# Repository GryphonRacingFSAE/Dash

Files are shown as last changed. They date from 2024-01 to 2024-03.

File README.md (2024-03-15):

# Gryphon Racing Dash

## About

An electronic dash for Gryphon Racing Vechicles 22-Present

## Installing Dependencies

### Setup for Raspberry Pi

Install all missing packages
```bash
sudo apt-get install python cmake libgl-dev libx11-dev libx11-xcb-dev libxcb-util-dev m4 libffi-dev
```

Ensure that the can interface on the RPi is active
```bash
sudo ip link set can0 up type can bitrate 1000000 # 1 mbps speed
```

### Setup for Windows

- Install [Python](https://docs.python.org/3/using/windows.html#using-python-on-windows) & ensure it is installed to PATH.
- Install [CMake](https://cmake.org/download/) & ensure it is installed to PATH.
- Install [Visual Studio 2022](https://visualstudio.microsoft.com/) & ensure the Desktop Development C++ extension is installed.

### Setup for MacOS
- Ensure python3 version is up to date >3.7
- Install [CMake](https://cmake.org/download/) & ensure it is installed to PATH.

### Universal
- Install conan via pip
```bash
python -m pip install conan==1.60.0 # or python3 on MacOS
```

## Installing Build Dependencies

Run the conan install script (`-pr` is the profile being used, the options are found in [ConanProfiles](./ConanProfiles/))
```bash
# Windows VS2022
conan install . -if build -pr:h=ConanProfiles/VS2022-Debug.ini -pr:b=ConanProfiles/VS2022-Debug.ini --build=missing -o dev="front"

# MacOS clang 14
conan install . -if build -pr:h=ConanProfiles/MacOS-clang-Debug.ini -pr:b=ConanProfiles/MacOS-clang-Debug.ini --build=missing -o dev="front"

# RPi 4b (gcc 10.2)
conan install . -if build -pr:h=ConanProfiles/pi4b-Debug.ini -pr:b=ConanProfiles/pi4b-Debug.ini --build=missing -o dev="full"

# RPi 1.2 b+ (gcc 10.2)
conan install . -if build -pr:h ConanProfiles/pib+-Release.ini -pr:b ConanProfiles/pib+-Release.ini --build=missing

# Linux gcc 12
conan install . -if build -pr:h=ConanProfiles/Linux-gcc-12-Debug.ini -pr:b=ConanProfiles/Linux-gcc-12-Debug.ini --build=missing -o dev="full"
```

* If building with `dev="back"`, Qt is not a requirement

## Building
- Run the conan build script & executables will be found in the build/bin folder.

```bash
conan build -if build .
```

## Running

```bash
source build/activate_run.sh # RPi (maybe required on other linux distros)
./build/Debug/bin/GryphonDash #(This runs the executable on RPi)
./build/bin/GryphonDash.exe #(This is to run the executable on windows)
source build/deactivate_run.sh # RPi (maybe required on other linux distros)
```

## Branch rules

- Name your branch as follows: `firstname/branchtopic`, ex. `dallas/move-from-previous-repo`
- `main` is a protected branch, and thus needs a PR to approve merging with it.

## CAN reservations

| Item | Reserved CAN Addresses |
|-|-|
| Motor Controller | 0x0A0-0x0CF |
| VCU | 0x0D0-0x0DF |
| BMS | 0x0E0-0x0EF |

## Building For RPI1.2

```bash
docker build
docker run
docker cp # copy artifacts back to userspace
```

## Resources

* [<linux/can.h>](https://github.com/torvalds/linux/blob/master/include/uapi/linux/can.h)
* [SocketCAN Intro](https://copperhilltech.com/what-is-socketcan/)
* [PiCAN1](https://copperhilltech.com/pican-with-gps-gyro-accelerometer-can-bus-board-for-raspberry-pi/)/[PiCAN2](https://copperhilltech.com/pican-2-can-bus-interface-for-raspberry-pi/)
* [Raspberry Pi w/ CanBus](https://www.hackster.io/youness/how-to-connect-raspberry-pi-to-can-bus-b60235)
* Not used, but good cross reference for the SocketCAN intro: [socketcan-cpp](https://github.com/siposcsaba89/socketcan-cpp)

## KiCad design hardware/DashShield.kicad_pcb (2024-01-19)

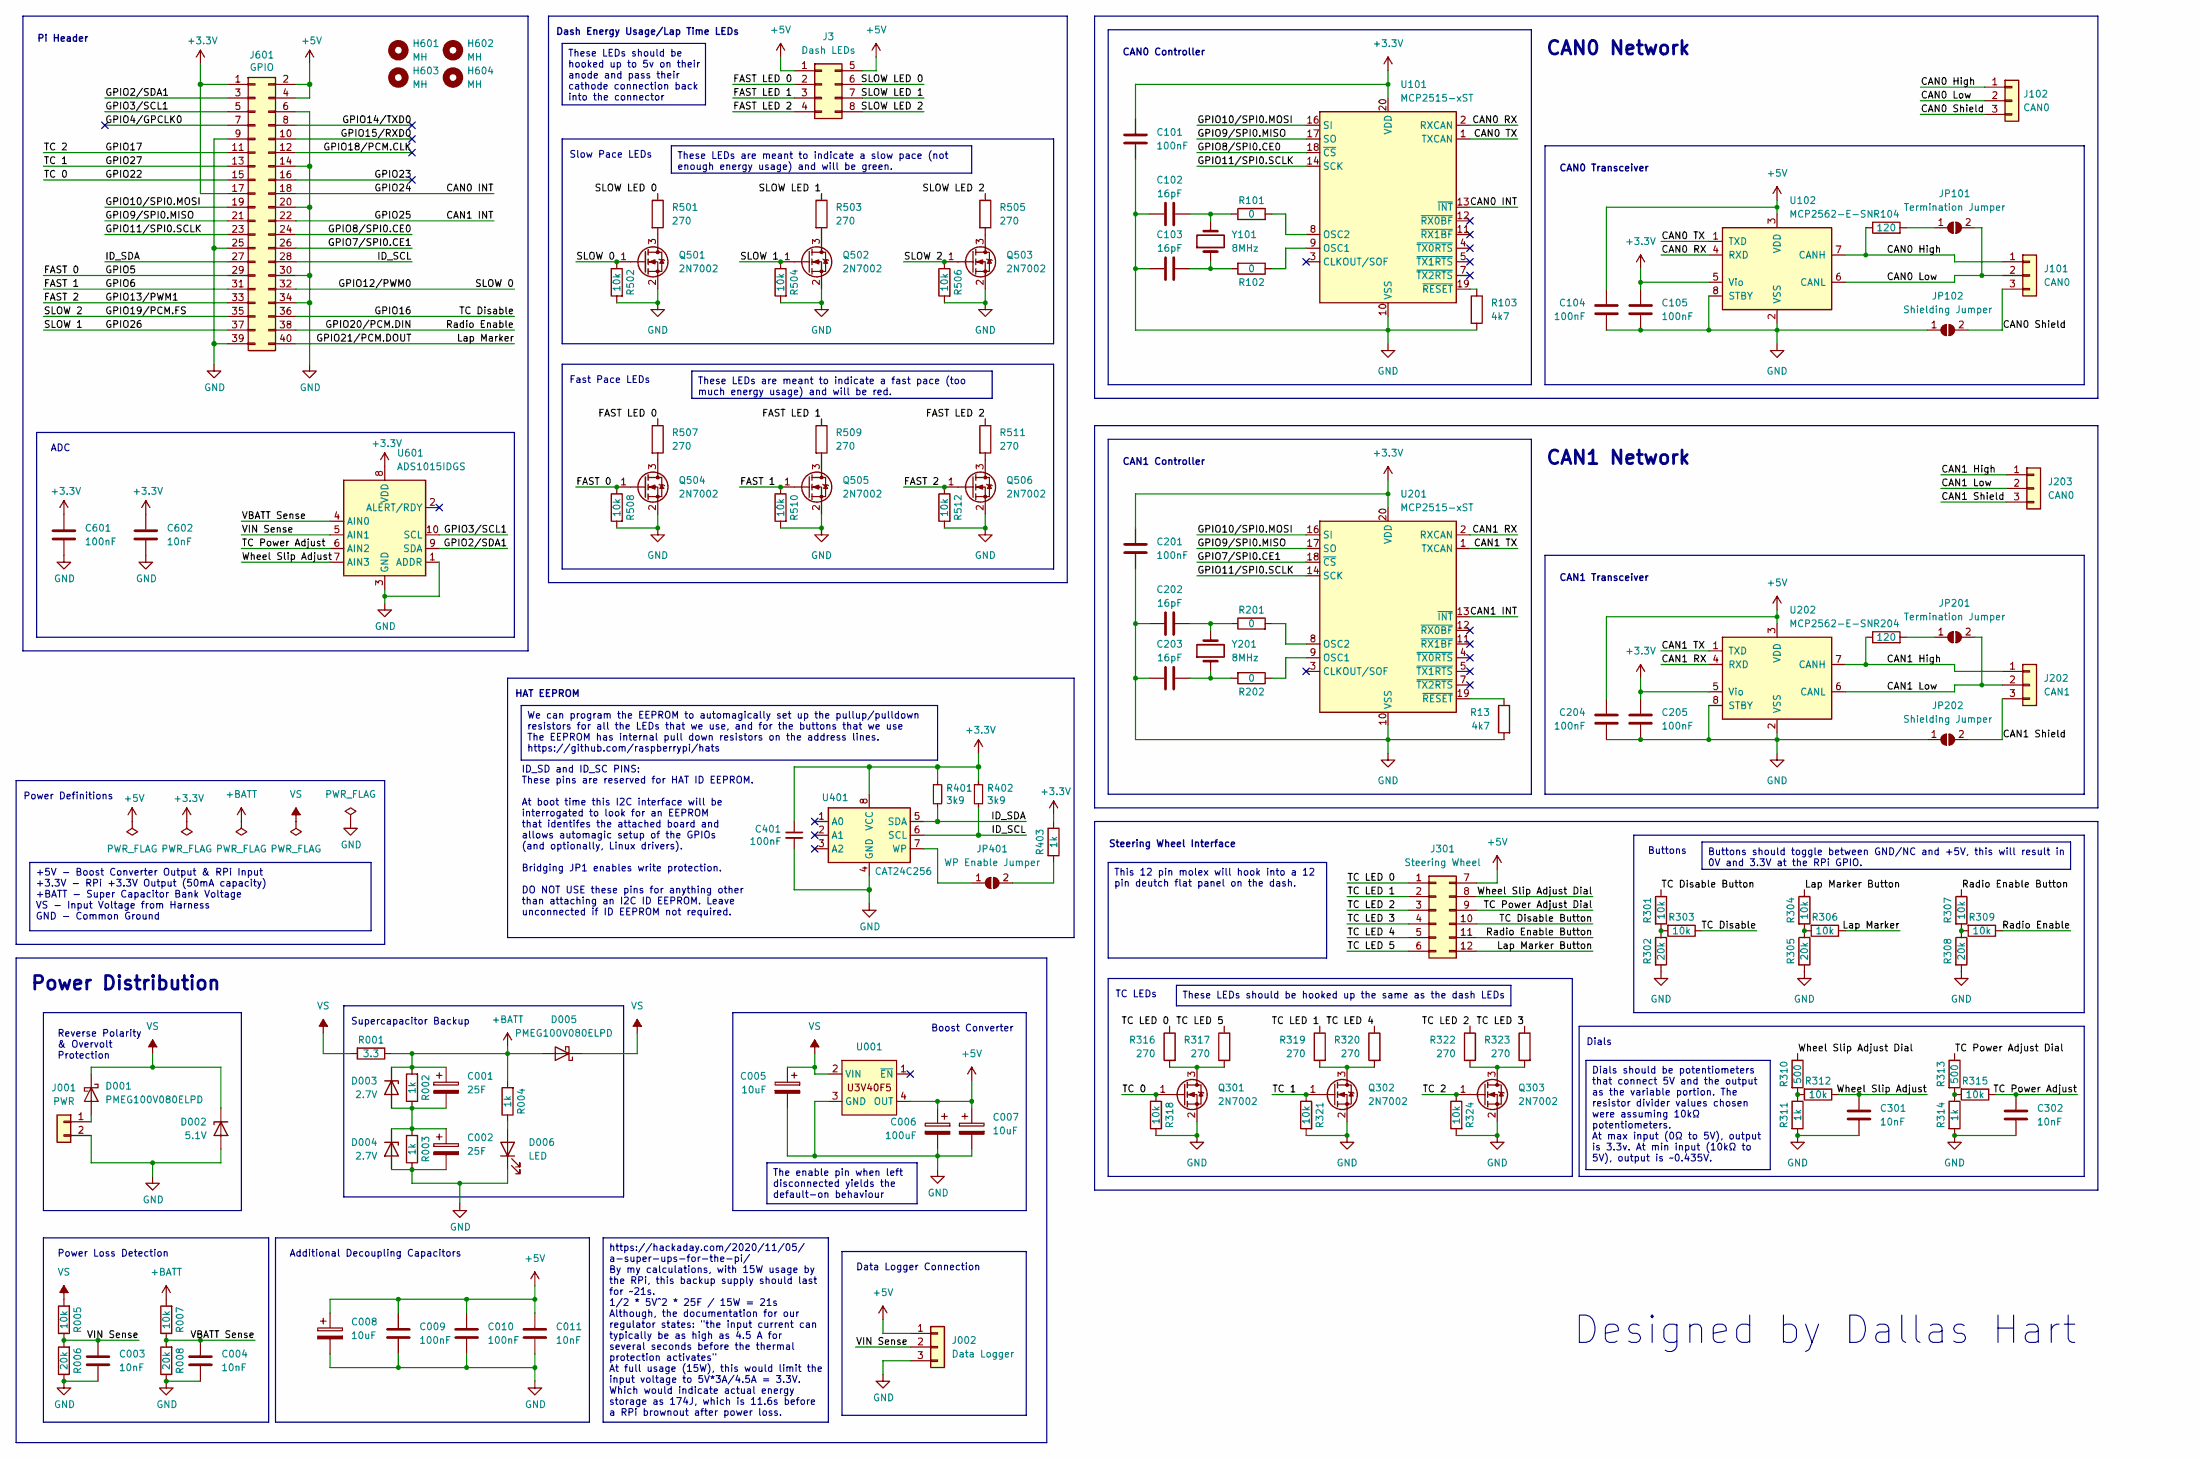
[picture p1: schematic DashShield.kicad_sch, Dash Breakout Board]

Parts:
C001, C002: 25F; CP_Radial_D16.0mm_P7.50mm
C003, C004, C011, C301, C302, C602: 10nF; C_0603_1608Metric
C005, C007, C008: 10uF; CP_Radial_D5.0mm_P2.50mm
C006: 100uF; CP_Radial_D5.0mm_P2.50mm
C009, C010, C101, C104, C105, C201, C204, C205, C401, C601: 100nF; C_0603_1608Metric
C102, C103, C202, C203: 16pF; C_0603_1608Metric
D001, D005: PMEG100V080ELPD; Nexperia_CFP15_SOT-1289
D002: 5.1V; D_SMA
D003, D004: 2.7V; SOT-23
D006: LED; LED_0603_1608Metric
H601, H602, H603, H604: MH; MountingHole_2.7mm_M2.5_Pad
J001: PWR; Molex_Micro-Fit_3.0_43650-0215_1x02_P3.00mm_Vertical
J002: Data Logger; Molex_Micro-Fit_3.0_43650-0315_1x03_P3.00mm_Vertical
J3: Dash LEDs; Molex_Micro-Fit_3.0_43045-0812_2x04_P3.00mm_Vertical
J101, J102, J203: CAN0; Molex_Micro-Fit_3.0_43650-0315_1x03_P3.00mm_Vertical
J202: CAN1; Molex_Micro-Fit_3.0_43650-0315_1x03_P3.00mm_Vertical
J301: Steering Wheel; Molex_Micro-Fit_3.0_43045-1212_2x06_P3.00mm_Vertical
J601: GPIO; PinSocket_2x20_P2.54mm_Vertical
JP101, JP201: Termination Jumper; SolderJumper-2_P1.3mm_Open_RoundedPad1.0x1.5mm
JP102, JP202: Shielding Jumper; SolderJumper-2_P1.3mm_Open_RoundedPad1.0x1.5mm
JP401: WP Enable Jumper; SolderJumper-2_P1.3mm_Open_RoundedPad1.0x1.5mm
Q301, Q302, Q303, Q501, Q502, Q503, Q504, Q505, Q506: 2N7002; SOT-23
R001: 3.3; R_0603_1608Metric
R002, R003, R004, R311, R314, R403: 1k; R_0603_1608Metric
R005, R007, R301, R303, R304, R306, R307, R309, R312, R315, R318, R321, R324, R502, R504, R506, R508, R510, R512: 10k; R_0603_1608Metric
R006, R008, R302, R305, R308: 20k; R_0603_1608Metric
R13, R103: 4k7; R_0603_1608Metric
R101, R102, R201, R202: 0; R_0603_1608Metric
R104, R204: 120; R_0603_1608Metric
R310, R313: 500; R_0603_1608Metric
R316, R317, R319, R320, R322, R323, R501, R503, R505, R507, R509, R511: 270; R_0603_1608Metric
R401, R402: 3k9; R_0603_1608Metric
U001: U3V40x
U101, U201: MCP2515-xST; TSSOP-20_4.4x6.5mm_P0.65mm
U102, U202: MCP2562-E-SN; SOIC-8_3.9x4.9mm_P1.27mm
U401: CAT24C256; SOIC-8_3.9x4.9mm_P1.27mm
U601: ADS1015IDGS; TSSOP-10_3x3mm_P0.5mm
Y101, Y201: 8MHz; Crystal_C38-LF_D3.0mm_L8.0mm_Vertical

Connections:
+3.3V: C101.1, C105.1, C201.1, C205.1, C401.1, C601.1, C602.1, J601.1, J601.17, R401.1, R402.1, R403.1, U101.20 (VDD), U102.5 (Vio), U201.20 (VDD), U202.5 (Vio), U401.8 (VCC), U601.8 (VDD)
+5V: C006.1, C007.1, C008.1, C009.1, C010.1, C011.1, C104.1, C204.1, J002.1, J3.1, J3.5, J301.7, J601.2, J601.4, U001.4 (OUT), U102.3 (VDD), U202.3 (VDD)
+BATT: C001.1, D003.3 (K), D005.1 (A), D005.2 (A), R001.1, R002.2, R004.2, R007.2
/CAN0 High: J101.1, J102.1, R104.1, U102.7 (CANH)
/CAN0 INT: J601.18, U101.13 (~INT)
/CAN0 Low: J101.2, J102.2, JP101.2 (B), U102.6 (CANL)
/CAN0 RX: U101.2 (RXCAN), U102.4 (RXD)
/CAN0 Shield: J101.3, J102.3, JP102.2 (B)
/CAN0 TX: U101.1 (TXCAN), U102.1 (TXD)
/CAN1 High: J202.1, J203.1, R204.1, U202.7 (CANH)
/CAN1 INT: J601.22, U201.13 (~INT)
/CAN1 Low: J202.2, J203.2, JP201.2 (B), U202.6 (CANL)
/CAN1 RX: U201.2 (RXCAN), U202.4 (RXD)
/CAN1 Shield: J202.3, J203.3, JP202.2 (B)
/CAN1 TX: U201.1 (TXCAN), U202.1 (TXD)
/FAST 0: J601.29, Q504.1 (G), R508.1
/FAST 1: J601.31, Q505.1 (G), R510.1
/FAST 2: J601.33, Q506.1 (G), R512.1
/FAST LED 0: J3.2, R507.1
/FAST LED 1: J3.3, R509.1
/FAST LED 2: J3.4, R511.1
/GPIO2/SDA1: J601.3, U601.9 (SDA)
/GPIO3/SCL1: J601.5, U601.10 (SCL)
/GPIO4/GPCLK0: J601.7
/GPIO7/SPI0.CE1: J601.26, U201.18 (~CS)
/GPIO8/SPI0.CE0: J601.24, U101.18 (~CS)
/GPIO9/SPI0.MISO: J601.21, U101.17 (SO), U201.17 (SO)
/GPIO10/SPI0.MOSI: J601.19, U101.16 (SI), U201.16 (SI)
/GPIO11/SPI0.SCLK: J601.23, U101.14 (SCK), U201.14 (SCK)
/GPIO12/PWM0: J601.32, Q501.1 (G), R502.1
/GPIO14/TXD0: J601.8
/GPIO15/RXD0: J601.10
/GPIO16: J601.36, R303.1
/GPIO17: J601.11, Q303.1 (G), R324.1
/GPIO18/PCM.CLK: J601.12
/GPIO19/PCM.FS: J601.35, Q503.1 (G), R506.1
/GPIO20/PCM.DIN: J601.38, R309.1
/GPIO21/PCM.DOUT: J601.40, R306.1
/GPIO22: J601.15, Q301.1 (G), R318.1
/GPIO23: J601.16
/GPIO26: J601.37, Q502.1 (G), R504.1
/GPIO27: J601.13, Q302.1 (G), R321.1
/ID_SCL: J601.28, R402.2, U401.6 (SCL)
/ID_SDA: J601.27, R401.2, U401.5 (SDA)
/Lap Marker Button: J301.12, R304.1
/Radio Enable Button: J301.11, R307.1
/SLOW LED 0: J3.6, R501.1
/SLOW LED 1: J3.7, R503.1
/SLOW LED 2: J3.8, R505.1
/TC Disable Button: J301.10, R301.1
/TC LED 0: J301.1, R316.1
/TC LED 1: J301.2, R319.1
/TC LED 2: J301.3, R322.1
/TC LED 3: J301.4, R323.1
/TC LED 4: J301.5, R320.1
/TC LED 5: J301.6, R317.1
/TC Power Adjust: C302.1, R315.1, U601.6 (AIN2)
/TC Power Adjust Dial: J301.9, R313.1
/VBATT Sense: C004.1, R007.1, R008.2, U601.4 (AIN0)
/VIN Sense: C003.1, J002.2, R005.1, R006.2, U601.5 (AIN1)
/Wheel Slip Adjust: C301.1, R312.1, U601.7 (AIN3)
/Wheel Slip Adjust Dial: J301.8, R310.1
GND: C002.2, C003.2, C004.2, C005.2, C006.2, C007.2, C008.2, C009.2, C010.2, C011.2, C101.2, C102.2, C103.1, C104.2, C105.2, C201.2, C202.2, C203.1, C204.2, C205.2, C301.2, C302.2, C401.2, C601.2, C602.2, D002.2 (A), D004.1 (A), D006.1 (K), J001.2, J002.3, J601.6, J601.9, J601.14, J601.20, J601.25, J601.30, J601.34, J601.39, JP102.1 (A), JP202.1 (A), Q301.2 (S), Q302.2 (S), Q303.2 (S), Q501.2 (S), Q502.2 (S), Q503.2 (S), Q504.2 (S), Q505.2 (S), Q506.2 (S), R003.1, R006.1, R008.1, R13.2, R103.2, R302.2, R305.2, R308.2, R311.2, R314.2, R318.2, R321.2, R324.2, R502.2, R504.2, R506.2, R508.2, R510.2, R512.2, U001.3 (GND), U101.10 (VSS), U102.2 (VSS), U102.8 (STBY), U201.10 (VSS), U202.2 (VSS), U202.8 (STBY), U401.4 (GND), U601.1 (ADDR), U601.3 (GND)
unnamed: C102.1, R101.1, Y101.2
unnamed: C103.2, R102.2, Y101.1
unnamed: C202.1, R201.1, Y201.2
unnamed: C203.2, R202.2, Y201.1
unnamed: C001.2, C002.1, D003.1 (A), D004.3 (K), R002.1, R003.2
unnamed: D006.2 (A), R004.1
unnamed: D001.1 (A), D001.2 (A), J001.1
unnamed: JP101.1 (A), R104.2
unnamed: JP201.1 (A), R204.2
unnamed: JP401.1 (A), U401.7 (WP)
unnamed: JP401.2 (B), R403.2
unnamed: Q301.3 (D), R316.2, R317.2
unnamed: Q302.3 (D), R319.2, R320.2
unnamed: Q303.3 (D), R322.2, R323.2
unnamed: Q501.3 (D), R501.2
unnamed: Q502.3 (D), R503.2
unnamed: Q503.3 (D), R505.2
unnamed: Q504.3 (D), R507.2
unnamed: Q505.3 (D), R509.2
unnamed: Q506.3 (D), R511.2
unnamed: R301.2, R302.1, R303.2
unnamed: R304.2, R305.1, R306.2
unnamed: R307.2, R308.1, R309.2
unnamed: R310.2, R311.1, R312.2
unnamed: R313.2, R314.1, R315.2
unnamed: R102.1, U101.9 (OSC1)
unnamed: R101.2, U101.8 (OSC2)
unnamed: R103.1, U101.19 (~RESET)
unnamed: R202.1, U201.9 (OSC1)
unnamed: R201.2, U201.8 (OSC2)
unnamed: R13.1, U201.19 (~RESET)
VS: C005.1, D001.3 (K), D002.1 (K), D005.3 (K), R001.2, R005.2, U001.2 (VIN)

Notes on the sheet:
https://hackaday.com/2020/11/05/ a-super-ups-for-the-pi/ By my calculations, with 15W usage by the RPi, this backup supply should last for ~21s. 1/2 * 5V^2 * 25F / 15W = 21s Although, the documentation for our regulator states: "the input current can typically be as high as 4.5 A for several second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
These LEDs should be hooked up to 5v on their anode and pass their cathode connection back into the connector
Buttons should toggle between GND/NC and +5V, this will result in 0V and 3.3V at the RPi GPIO.
We can program the EEPROM to automagically set up the pullup/pulldown resistors for all the LEDs that we use, and for the buttons that we use The EEPROM has internal pull down resistors on the address lines. https://github.com/raspberrypi/hats
The enable pin when left disconnected yields the default-on behaviour
These LEDs are meant to indicate a slow pace (not enough energy usage) and will be green.
Dials should be potentiometers that connect 5V and the output as the variable portion. The resistor divider values chosen were assuming 10kΩ potentiometers. At max input (0Ω to 5V), output is 3.3v. At min input (10kΩ to 5V), output is ~0.435V.
This 12 pin molex will hook into a 12 pin deutch flat panel on the dash.
+5V - Boost Converter Output & RPi Input +3.3V - RPi +3.3V Output (50mA capacity) +BATT - Super Capacitor Bank Voltage VS - Input Voltage from Harness GND - Common Ground
These LEDs should be hooked up the same as the dash LEDs
These LEDs are meant to indicate a fast pace (too much energy usage) and will be red.
Power Loss Detection
Power Definitions
CAN1 Controller
Reverse Polarity & Overvolt Protection
Dials
Designed by Dallas Hart
ID_SD and ID_SC PINS: These pins are reserved for HAT ID EEPROM. At boot time this I2C interface will be interrogated to look for an EEPROM that identifes the attached board and allows automagic setup of the GPIOs (and optionally, Linux drivers). Bridging JP1 enables write protection. DO NOT USE th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
ADC
Data Logger Connection
Buttons
Power Distribution
Fast Pace LEDs
TC LEDs
CAN1 Transceiver
Supercapacitor Backup
Steering Wheel Interface
CAN1 Network
Dash Energy Usage/Lap Time LEDs
HAT EEPROM
Slow Pace LEDs
CAN0 Network
Pi Header
CAN0 Transceiver
CAN0 Controller
Additional Decoupling Capacitors
Boost Converter

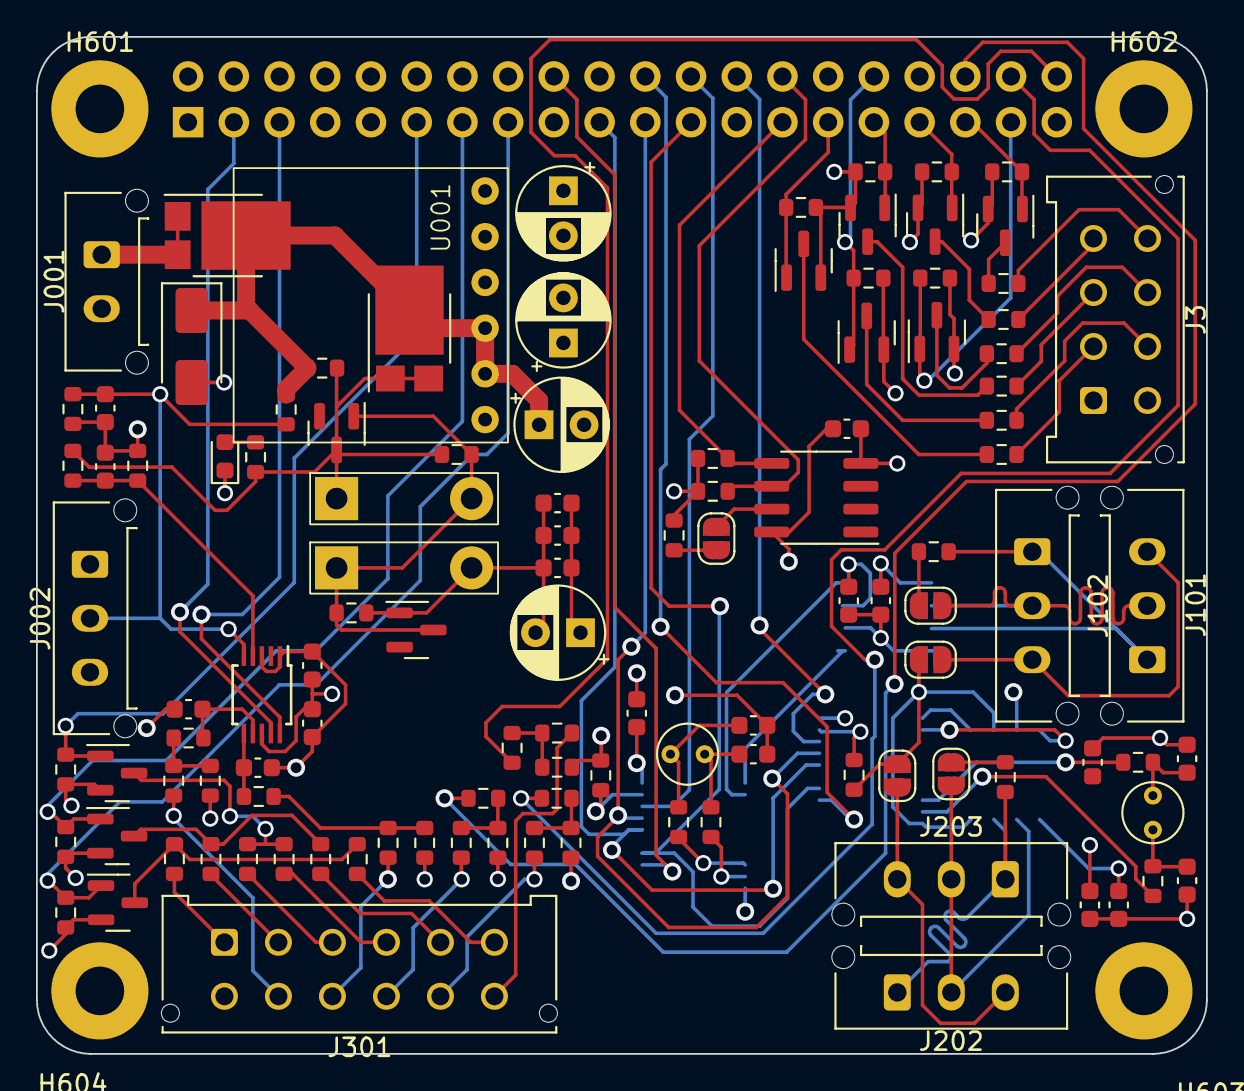
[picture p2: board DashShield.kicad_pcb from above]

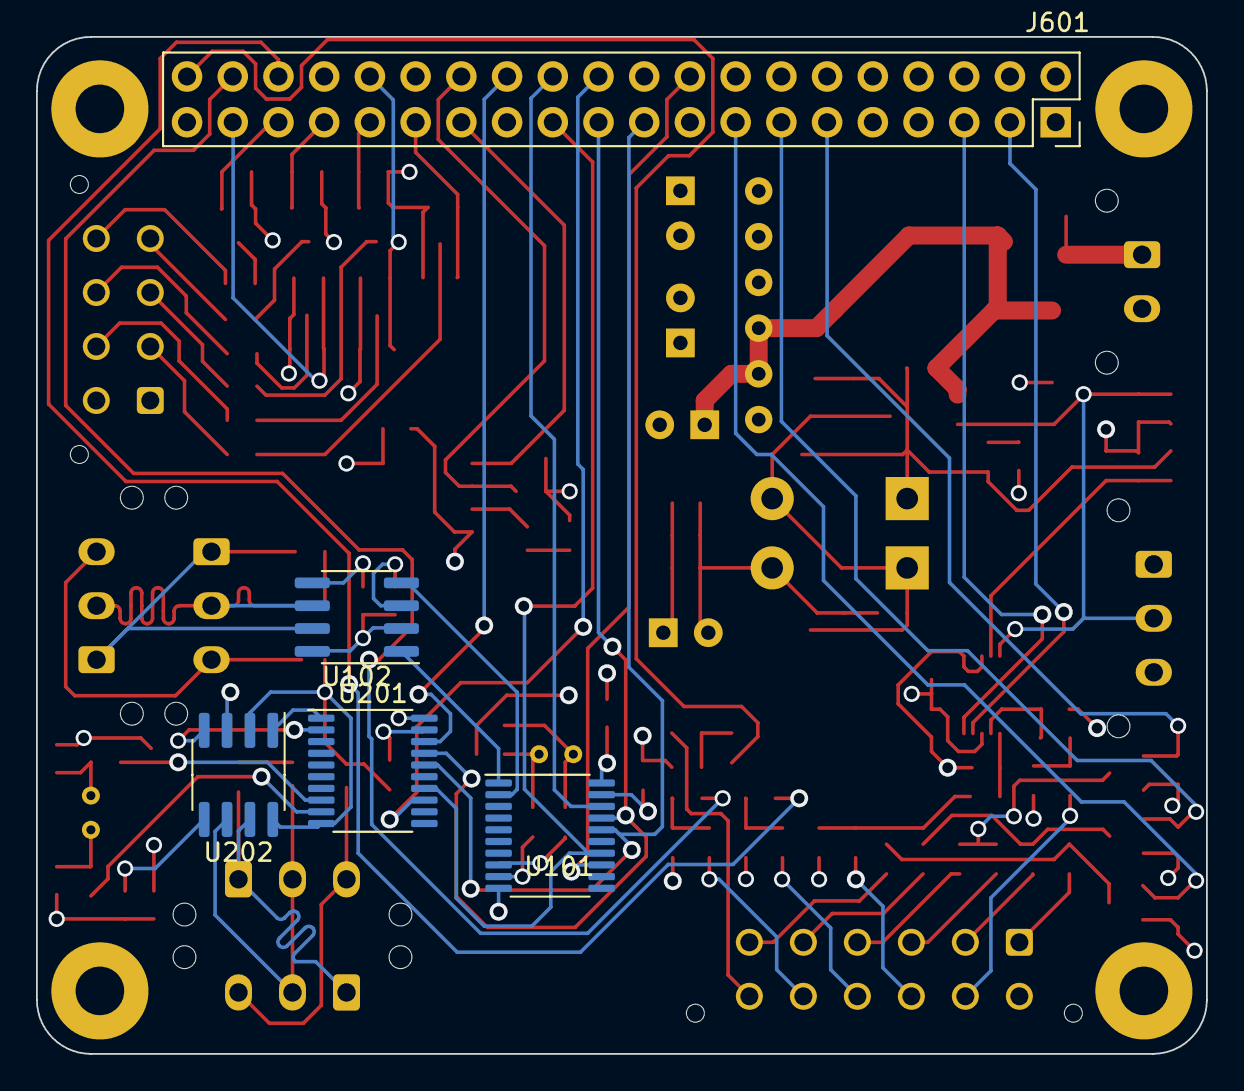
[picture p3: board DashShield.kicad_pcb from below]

Board: 4 copper layers, 65.0 x 56.5 mm, 123 parts (5 on the bottom side), 90 nets.

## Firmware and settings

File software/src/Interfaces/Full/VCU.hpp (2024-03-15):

#pragma once

#include <DBCInterface.hpp>
#include <QObject>
#include <filesystem>
#include <fmt/ranges.h>
#include <limits>
#include <rapidcsv.h>
#include <tools.hpp>

namespace real {

class VCU : public QObject, public CAN::DBCInterface<VCU> {
    Q_OBJECT
    Q_PROPERTY(QList<int> currentTorqueMap MEMBER m_current_torque_map NOTIFY currentTorqueMapChanged)
    Q_PROPERTY(int profileId MEMBER m_profile_id NOTIFY profileIdChanged)
    Q_PROPERTY(int maxTorque MEMBER torque_map_max CONSTANT)
    Q_PROPERTY(int minTorque MEMBER torque_map_min CONSTANT)
    Q_PROPERTY(QList<float> currentTcTune MEMBER m_current_tc_tune NOTIFY currentTcTuneChanged)
    Q_PROPERTY(int tcTuneId MEMBER m_tc_tune_id NOTIFY tcTuneIdChanged)
  public:
    VCU(const std::string& torque_map_directory = "")
        : QObject(nullptr), m_torque_map_directory(torque_map_directory), m_profile_id(0), m_tc_tune_id(0), DBCInterface("VCU.dbc") {

        if (!std::filesystem::exists(m_torque_map_directory) || !std::filesystem::is_directory(m_torque_map_directory)) {
            fmt::print("Torque map directory doesn't exist!");
            throw "Bricked hard";
        }

        connect(this, &VCU::profileIdChanged, &VCU::readTorqueMapCSV);
        connect(this, &VCU::tcTuneIdChanged, &VCU::readTcTuneCSV);

        readTorqueMapCSV();
        readTcTuneCSV();

        //pedal position
        can_signal_dispatch["ACCELERATOR_POSITION"] = &VCU::newAcceleratorPos;
        can_signal_dispatch["BRAKE_PRESSURE"] = &VCU::newAcceleratorPos;

        // Startup HW interface
        this->CAN::Interface::startReceiving("can0", VCU::filters, VCU::num_of_filters, VCU::timeout_ms);
    }

    Q_INVOKABLE void saveTorqueMapCSV(QList<int> torque_map) {
        auto save_path = m_torque_map_directory / fmt::format("torque_map_{}.csv", m_profile_id);
        rapidcsv::Document doc(save_path.string(), rapidcsv::LabelParams(-1, -1));
        for (qsizetype i = 0; i < torque_map.size(); i++) {
            doc.SetCell(i % 14, i / 14, torque_map.at(i));
        }
        doc.Save();
    }

    Q_INVOKABLE void saveTcTuneCSV(QList<float> tc_tune) {
        auto save_path = m_torque_map_directory / fmt::format("tc_tune_{}.csv", m_tc_tune_id);
        rapidcsv::Document doc(save_path.string(), rapidcsv::LabelParams(-1, -1));
        for (qsizetype i = 0; i < tc_tune.size(); i++) {
            doc.SetCell(i % 14, i / 14, tc_tune.at(i));
        }
        doc.Save();
    }

  public slots:
    void readTorqueMapCSV() {
        m_current_torque_map.clear();
        auto read_path = m_torque_map_directory / fmt::format("torque_map_{}.csv", m_profile_id);
        rapidcsv::Document doc(read_path.string(), rapidcsv::LabelParams(-1, -1));
        for (size_t i = 0; i < doc.GetRowCount(); i++) {
            for (const auto cell : doc.GetRow<int>(i)) {
                m_current_torque_map.push_back(cell);
            }
        }
        emit currentTorqueMapChanged();
    }

    void readTcTuneCSV() {
        m_current_tc_tune.clear();
        auto read_path = m_torque_map_directory / fmt::format("tc_tune_{}.csv", m_tc_tune_id);
        rapidcsv::Document doc(read_path.string(), rapidcsv::LabelParams(-1, -1));
        for (const auto cell : doc.GetRow<float>(0)) {
            m_current_tc_tune.push_back(cell);
        }

        emit currentTcTuneChanged();
    }

  signals:
    void currentTorqueMapChanged();
    void currentTcTuneChanged();
    void profileIdChanged();
    void tcTuneIdChanged();
    void newAcceleratorPos(float pos);
    void newBrakePressure(float psi);

  public:
    Q_INVOKABLE void sendTorqueMap(QList<int> torque_map) {
        uint8_t percent_division_count = 11; // 0-100 in increments of 10%
        uint8_t speed_division_count = 14;   // 0-130 in increments of 10kmph
        unsigned int expected_data_points_in_torque_map = percent_division_count * speed_division_count;
        if (expected_data_points_in_torque_map > 255) {
            fmt::print("Number of data points inside torque map ({}) exceeds limit of 255\n", expected_data_points_in_torque_map);
            return;
        }
        uint8_t num_of_torque_map_data_points = static_cast<uint8_t>(expected_data_points_in_torque_map);

        if (torque_map.size() != num_of_torque_map_data_points) {
            fmt::print("QML torque map size ({}) != required torque map size ({})\n", torque_map.size(), num_of_torque_map_data_points);
            return;
        }

        std::vector<uint8_t> transaction;
        transaction.reserve(num_of_torque_map_data_points);
        for (int torque : torque_map) {
            // Verify torque is within bounds
            if (torque > torque_map_max || torque < torque_map_min) {
                fmt::print("Torque map values out of bounds\n");
                return;
            }
            int adjusted_data_point = torque - torque_map_offset;                  // Readjust torque values to between -128 and 127
            int8_t data_point = static_cast<int8_t>(adjusted_data_point);          // This is safe as values should already
                                                                                   // be within the bounds of this data type
            uint8_t encoded_data_point = *reinterpret_cast<uint8_t*>(&data_point); // Encode the int8_t into a uint8_t
            transaction.push_back(encoded_data_point);
        }

        // Headers must be 8 bytes long
        // Data for 2D arrays should be sent in Row Major Order
        auto header = std::array<uint8_t, 8>{
            0x00,                          // Dash is ID: 0
            'T',                           // Initiate upload transaction for (T)orque map
            num_of_torque_map_data_points, // Size of transaction in bytes
            0,                             // reserved
            // The last 4 bytes is reserved for data specific to the transaction
            speed_division_count,                                  // Count of data points on speed axis (X axis or number of
                                                                   // columns)
            percent_division_count,                                // Count of data points on percent axis (Y axis or number of
                                                                   // rows)
            *reinterpret_cast<const uint8_t*>(&torque_map_offset), // Send offset so VCU can decode the values
            0                                                      // Padding
        };

        if (sendTransaction(header, transaction) != RetCode::Success) {
            fmt::print("Something went wrong sending the transaction");
        }
    }

    Q_INVOKABLE void sendTcTune(QList<float> tc_tune) {
        // TODO
    }
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

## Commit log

2023-10-16 chore: upload progress
    [DashShield.kicad_pcb, DashShield.kicad_sch]
2023-10-21 Chore-Upload progress
    [DashShield.kicad_pcb, DashShield.kicad_sch]
2023-10-30 feat: add ADC and data logger connector
    [DashShield.kicad_sch]
2024-01-19 feat: added pours & pass-through for CAN0&CAN1
    [DashShield.kicad_pcb, DashShield.kicad_sch]
